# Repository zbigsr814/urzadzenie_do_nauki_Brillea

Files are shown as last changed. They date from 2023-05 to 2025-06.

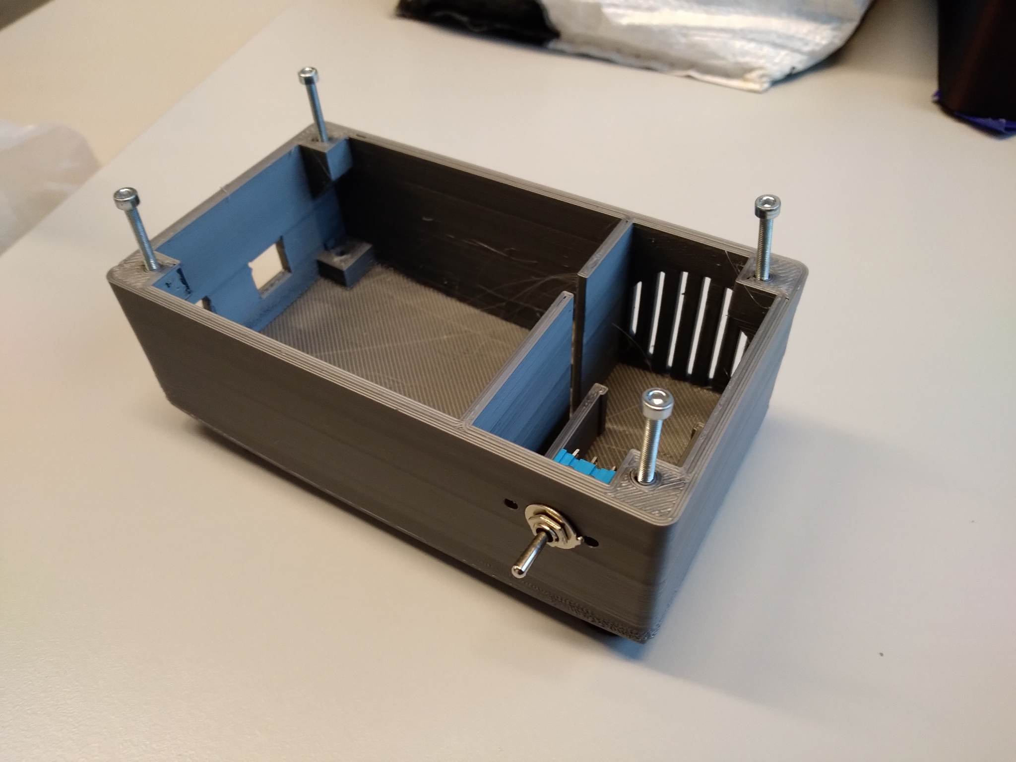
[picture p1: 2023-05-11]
zdjęcia i filmy/7.jpg

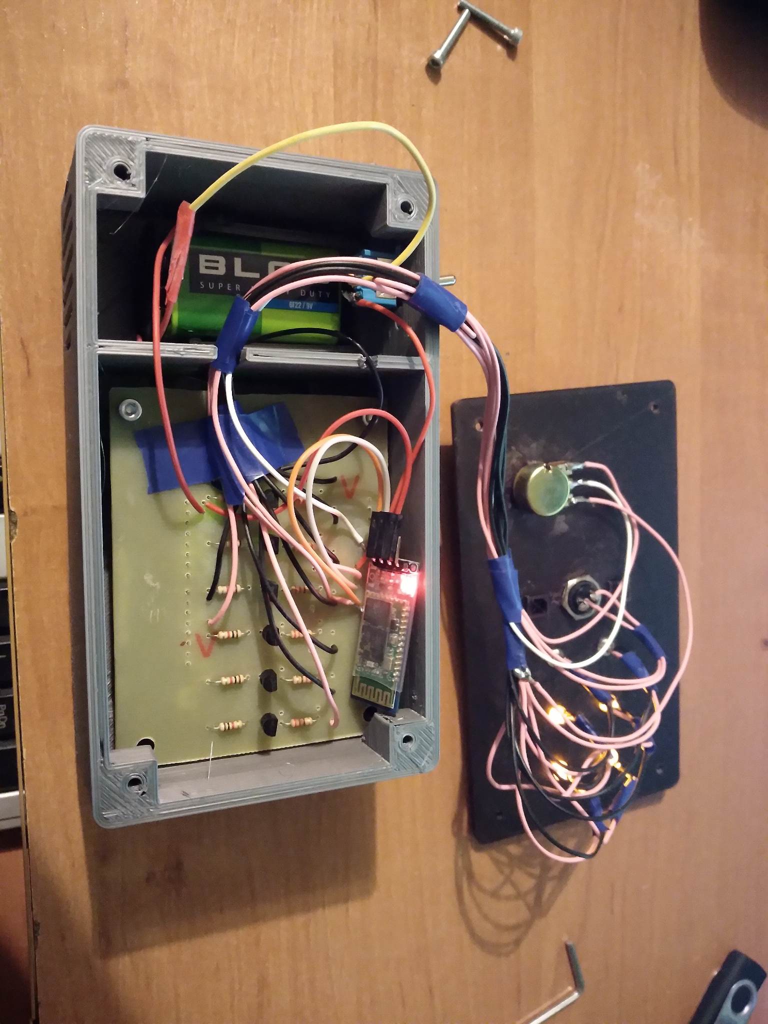
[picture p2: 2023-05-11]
zdjęcia i filmy/4.jpg

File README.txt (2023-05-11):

# urzadzenie_do_nauki_Brillea

Wykonany projekt został zrealizowany dla koła naukowego Integral Senso na PŚ. 
 
Jest to urządzenie do nauki języka Brillea dla dzieci niedowidzących. Urządzenie odbierało dane z czujnika HC-05 (wyrazy/zdania) przesłane z telefonu (przez sieć Bluetooth) i wyświetlał je w alfabecie Brillea. Należało pobrać aplikację na telefon która funkcjonyje jako terminal Bluetooth. Wyświetlanie liter alfabetu Brillea odbywało się przez sześć diod, iteracja po kolejnych literach przez wciśnięcie przycisku. Regulacja jasności świecenia diodami potencjometrem. Sygnał z potencjometru trafiał na wejście analogowe Arduino. Regulacja świecenia diod przez PWM pinów wyjściowych Arduino. Zasilanie wewnętrzne bateryjne oraz zewnętrzne przewodem USB do źródła zasilania. Projekt obejmował: 

- Wykonanie programu na Arduino. Program odpowiedzialny za: obsługę odbioru danych przez Bluetooth, wysterowanie odpowiednich diod, sterowanie jasnością świecenia, odbiór danych z potencjometru.

- Projekt płytki PCB w Kicadzie. Płytka odpowiada m.in. za wzmocnienie sygnałów GPIO Arduino przez zastosowanie tranzystorów BC-547. Wzmocnione sygnały docierają na diody. Płytka pośredniczy między Arduino a resztą urządzenia. 
 
- Projekt obudowy urządzenia wykonanej w DesignSparks. Urządzenie miało być przeznaczone dla dzieci więc obudowa nie zawierała ostrych krawędzi, ścianki obudowy są odpowiednio grube. Wyznaczono sekcję dla zasilania bateryjnego i dla reszty elektroniki. Obudowę wykonano na drukarce 3D.

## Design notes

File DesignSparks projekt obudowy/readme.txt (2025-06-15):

Górna i dolna część zamodelowanej obudowy. Model następnie był poddany obróbce przez Cura Slicer aby uzyskać g-code do drukarki 3D. 
Modele obudowy w formacie stl można podpatrzeć klikając na nie. Do podglądu można też wykorzystać stronę: https://www.viewstl.com/
Plik w formacie rsdoc to zamodelowany projekt w programie Design Sparks

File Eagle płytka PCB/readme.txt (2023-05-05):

Pliki brd i sch w tym katalogu to gotowe pliki do uruchmienia w programie Kicad.

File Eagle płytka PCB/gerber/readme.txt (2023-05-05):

Model płytki PCB można zobaczyć na stronie: https://www.pcbway.com/project/OnlineGerberViewer.html

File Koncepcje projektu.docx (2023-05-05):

Cel projektu:

- budowa urządzenia dla dzieci, które miało im pomóc w nauce języka Brille’a. Zabawka ma służyć aby wywołać w dziecku pozytywne emocje, aby czymś te dziecko zająć oraz w celu dydaktyki i nauki nowego języka. Wstępnie dokonano różnego rodzaju koncepcji aby gotowe urządzenie spełniało szereg wymagań.

Postanowionymi wymaganiami było m.in.:

- niski koszt budowy urządzenia

- prosta zasada działania urządzenia

- urządzenie ma bezpośrednio oddziaływać na zmysły użytkownika (wzrok, odczuwanie itd.)

- wysoka wytrzymałość urządzenia

- możliwość konfiguracji przedstawiania danych wyjściowych

Pierwszym założeniem jakie przyjęto podczas realizacji projektu jest funkcja oddziaływania urządzenia na zmysł wzroku dziecka. Docelowo język Brille’a jest językiem którym posługują się osoby niewidome i niedowidzące. Postanowiono że istnieje szereg chorób tj. zaćma lub jaskra w wyniku których osoba stopniowo traci wzrok. Kiedy wzrok osoby jest jeszcze dostatecznie dobry to jest w stanie nauczyć się języka Brille’a za pomocą wzroku. Przykładowym sposobem jest wykorzystanie diod LED lub innego źródła światła aby oddziaływać na zmysł wzroku dziecka.

Realizacja projektu:

Platforma sprzętowa

W pierwszej kolejności należało określić jaka platforma sprzętowa zostanie wybrana. Poniższe platformy są dosyć popularne i łatwo dostępne. Dokonano rozważania między poniższymi platformami:

- Arduino – platforma programistyczna dla systemów wbudowanych oparta na prostym projekcie Open Hardware przeznaczonym dla mikrokontrolerów montowanych w pojedynczym obwodzie drukowanym, z wbudowaną obsługą układów wejścia/wyjścia oraz standaryzowanym językiem programowania.

Zalety: prosta budowa, przyjazny język programowania dla hobbystów, niska cena.

Wady: napisane programy zajmują więcej miejsca, programy są mało optymalne, mała ilość pamięci Flash, RAM, EEPROM

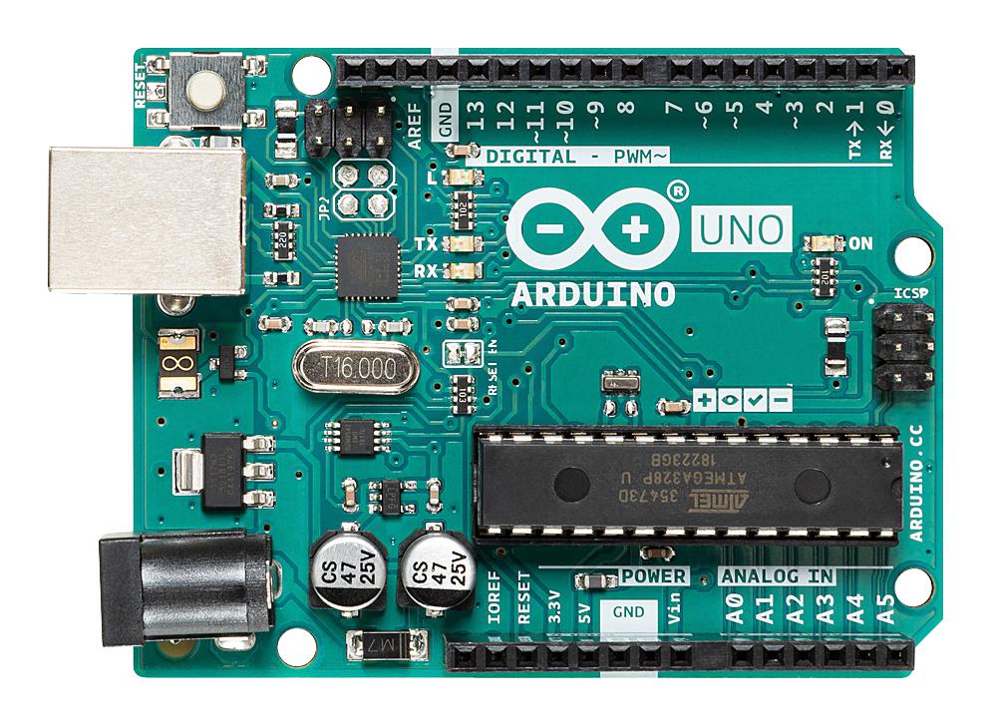
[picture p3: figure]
A000066 - Arduino - Płytka ewaluacyjna, MCU 8 bitów, Arduino Uno R3

Rys. x Arduino Uno

- STM32 - rodzina 32–bitowych mikrokontrolerów w układach scalonych produkowanych przez francusko-włoską firmę STMicroelectronics. Chipy STM32 są pogrupowane w różne, blisko spokrewnione serie, oparte na 32–bitowych procesorach ARM, takich jak Cortex-M7F, Cortex-M4F, Cortex-M3, Cortex-M0 + lub Cortex-M0.

Zalety: duża ilość pamięci RAM, EEPROM, Flash, wysoka częstotliwość taktowania, duża ilość urządzeń peryferyjnych, programowanie w C

Wady: wysoka cena płytek rozwojowych

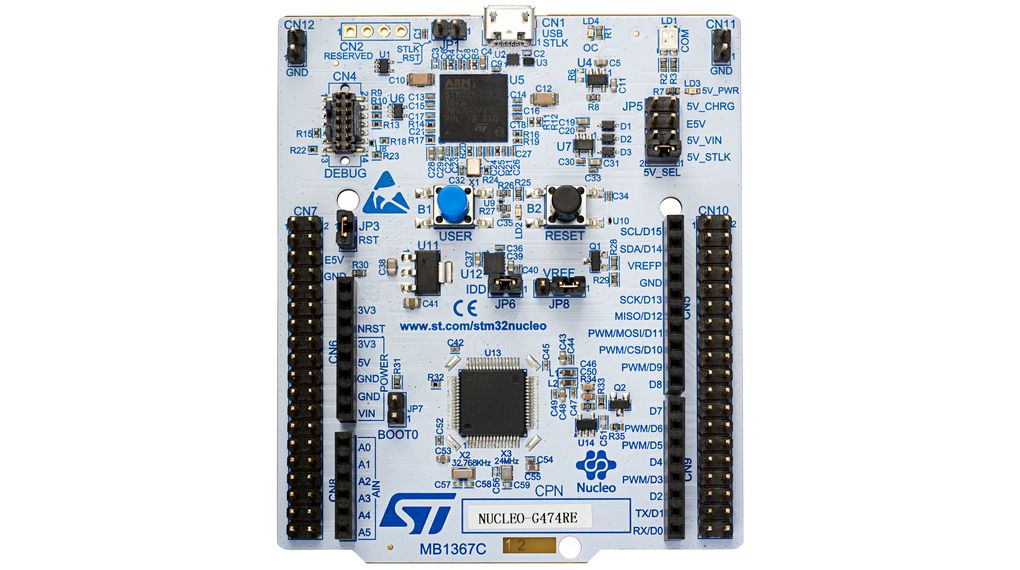
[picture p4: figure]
NUCLEO-L452RE-P | ST Płytka Nucleo STM32 512KB 160KB | Distrelec Polska

Rys. x STM32

- AVR - Mikrokontrolery AVR są popularne wśród hobbystów i amatorów, ze względu na łatwość programowania, a także łatwość uruchomienia. Do niektórych układów wystarczy podłączyć zasilanie, by stanowiły kompletny, programowalny system mikroprocesorowy. W połączeniu z dużymi obudowami typu DIP daje to rzadko spotykaną możliwość budowy prostszych układów mikroprocesorowych bez konieczności pracochłonnego przygotowywania płytki drukowanej.

Zalety: prosta budowa, programowanie w C, niska cena.

Wady: mała ilość pamięci Flash, RAM, EEPROM

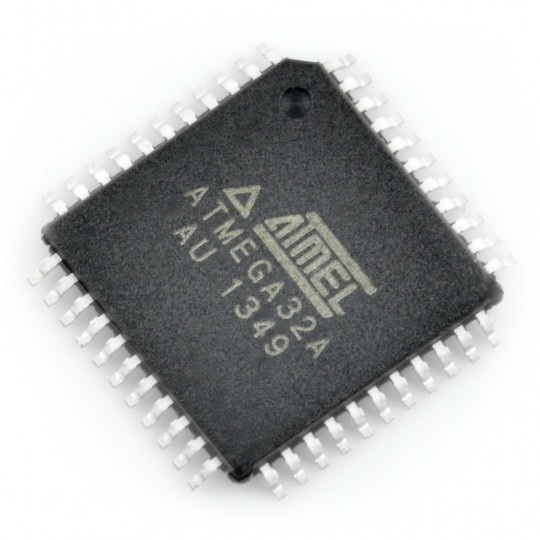
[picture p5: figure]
Mikrokontroler AVR - ATmega32A-AU SMD

Rys. x AVR

Na podstawie powyższych rozważań, zdecydowano się na platformę Arduino Uno. Arduino posiada prosty język programowania oraz cena nie jest wysoka. Dodatkowo wysoka częstotliwość taktowania czy duża ilość urządzeń peryferyjnych nie jest wymagana dla projektu jakim jest zabawka dla dzieci.

Źródło światła

W następnej kolejności skupiono się nad możliwymi źródła światła. Przyjęto że najlepszym rozwiązaniem będą diody LED. Diody muszą być w kolorze który będzie łatwo odbieranym przez dziecko. Diody muszą być w przezroczystej obudowie. Rozważano następujące rodzaje diod:

- diody w kolorze żółtym – kolor żółty jest łatwo odczytywanym przez dziecko. Ten kolor łatwo będzie kontrastował na ciemnym tle (na obudowie urządzenia w ciemnym kolorze)

- diody RGB – jest to rozwiązanie uniwersalne. Użytkownik będzie miał możliwość wybrania koloru wedle upodobania.

Dokonanym wyborem są diody LED w przezroczystej obudowie świecące kolorem żółtym. Wykorzystanie monochromatycznego światła jest wystarczające dla tego projektu. Dodatkową funkcjonalnością dodaną do projektu jest dodanie potencjometru, którym możemy regulować jasność świecenia diod.

Zasilanie

Rozważano następujące sposoby zasilania:

- zasilanie z USB – najbardziej uniwersalne rozwiązanie. Wystarczy przewód USB którym podłączymy się do urządzenia. Źródłem zasilania może być zewnętrzny powerbank lub zasilacz podłączony do sieci.

- zasilanie bateryjne – rozwiązanie do którego nie potrzeba dodatkowych przewodów lub zasilaczy. Wadą tego zastosowania jest częsta zmiana baterii na skutek używania urządzenia

- zasilanie z wewnętrznego powerbanka – kolejnym rozwiązaniem jest zamontowanie powerbanka wewnątrz obudowy. To rozwiązanie ma tą zaletę że powerbank pomieści dużą ilość prądu, konieczne będzie ładowanie z USB.

Dokonano wyboru dwóch powyższych opcji. Zastosowano zasilanie bateryjne oraz poprzez USB. Jeśli bateria się zużyje to należy ją wymienić, lecz będzie też można zasilić urządzenie z zewnętrznego powerbanka lub zasilacza.

Obudowa urządzenia

Zdecydowano się wykonać obudowę urządzenia z plastiku. Obudowę wykonano na drukarce 3D. Kolor obudowy musi być w ciemnym kolorze tak aby jasne świecące diody mogły kontrastować z ciemnym tłem.

Źródła:

https://www.google.com/url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 (https://www.google.com/url?psig=AOvVaw3-AJc7bmiJPXDSjU2i4-T9&cd=vfe)

https://www.google.com/url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 (https://www.google.com/url?psig=AOvVaw25d-h0V1c4RtG5vNDJ4lyy&cd=vfe)

https://botland.com.pl/avr-smd/160-mikrokontroler-avr-atmega32a-au-smd-5903351249935.html

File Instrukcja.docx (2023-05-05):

Instrukcja do urządzenia do nauki Brille’a z diodami.

1. W pierwszej kolejności należy włączyć urządzenie. Są na to dwa sposoby. Pierwszy sposób to przez zmianę położenia przełącznika z boku obudowy. Drugi sposób to podłączenie kabla USB do urządzenia. Drugi koniec kabla należy podłączyć do powerbanka lub do zasilacza. Jeśli urządzenie się załączy to jedna z diod kilkukrotnie zamiga.
2. W następnej kolejności należy na telefonie przejść do aplikacji Sklep Play. Należy odszukać i zainstalować aplikację: Bluetooth Terminal HC-05.

Rys. 1. Ikona aplikacji

Aplikację możemy pobrać też po wpisaniu poniższego linku do przeglądarki internetowej:

https://play.google.com/store/apps/details?id=project.bluetoothterminal

3. Po zainstalowaniu należy uruchomić aplikację. Na początku zostaniemy zapytani czy włączyć funkcję Bluetooth w telefonie. Należy zezwolić na włączenie Bluetooth.

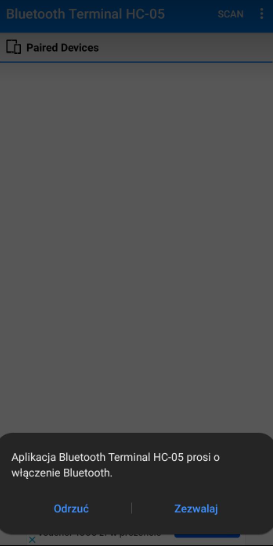
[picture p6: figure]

Rys. 2. Początkowy ekran w aplikacji

4. Następnie w aplikacji należy sparować się z urządzeniem HC-05:
5. Uruchomi się główne okno aplikacji. W miejscu „Enter ASCII Command” należy wpisać tekst jaki chcemy przesłać do urządzenia. Następnie klikamy przycisk „Send ASCII” w celu wysłania tekstu.

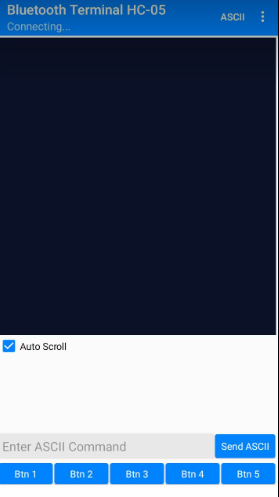
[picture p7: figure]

Rys. 3. Główne okno aplikacji

6. W tym momencie w urządzeniu powinny zapalić się diody odpowiadające wysłanemu wcześniej tekstowi. Diody świecą się zgodnie z alfabetem Brille’a. Aby przejść do następnej litery wysłanego tekstu, należy wcisnąć czerwony przycisk. Urządzenie ma możliwość regulowania jasności świecenia diod. Służy do tego pokrętło w dolnej części obudowy.
7. Po wyświetleniu wszystkich liter nadesłanego słowa, możemy wysłać nowy napis przez aplikację na telefonie.
8. Po zakończeniu użytkowania urządzenia należy je wyłączyć poprzez odłączenie przewodu USB (jeśli stosowano zewnętrzne zasilanie) lub zmienić pozycję przełącznika z boku obudowy (jeśli stosowano wewnętrzne bateryjne zasilanie).

Urządzenie posiada zasilanie bateryjne. Jeśli bateria jest rozładowana to urządzenie się nie włączy. Należy albo wymienić baterię (Należy odkręcić cztery śruby obudowy), albo zasilić urządzenie z zewnątrz poprzez kabel USB.

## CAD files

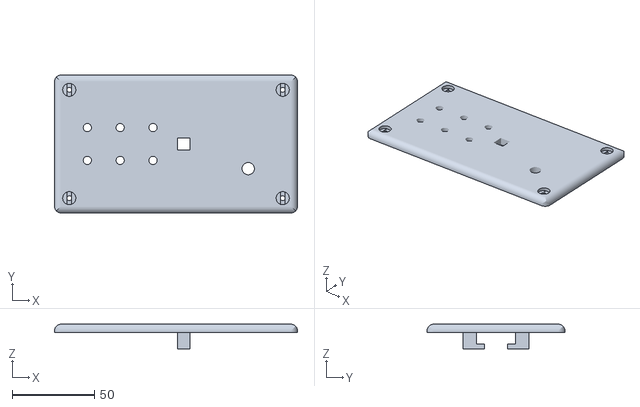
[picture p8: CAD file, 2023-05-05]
DesignSparks projekt obudowy/ObudowaGoraSTL.stl
148.0 x 84.0 x 15.0

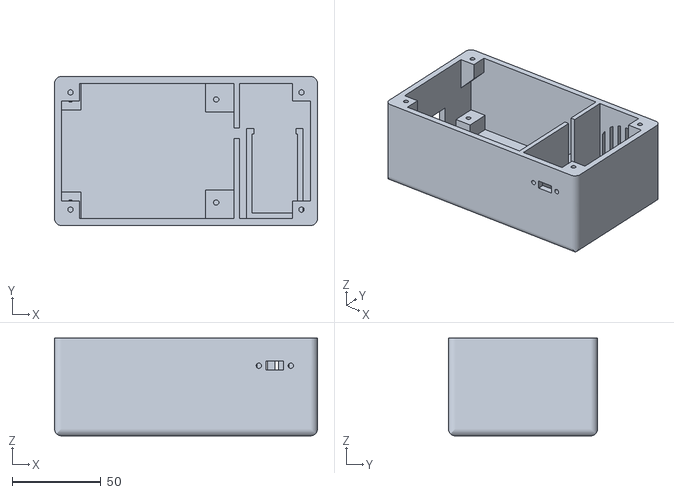
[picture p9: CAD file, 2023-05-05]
DesignSparks projekt obudowy/ObudowaSpodSTL.stl
148.0 x 84.0 x 55.0

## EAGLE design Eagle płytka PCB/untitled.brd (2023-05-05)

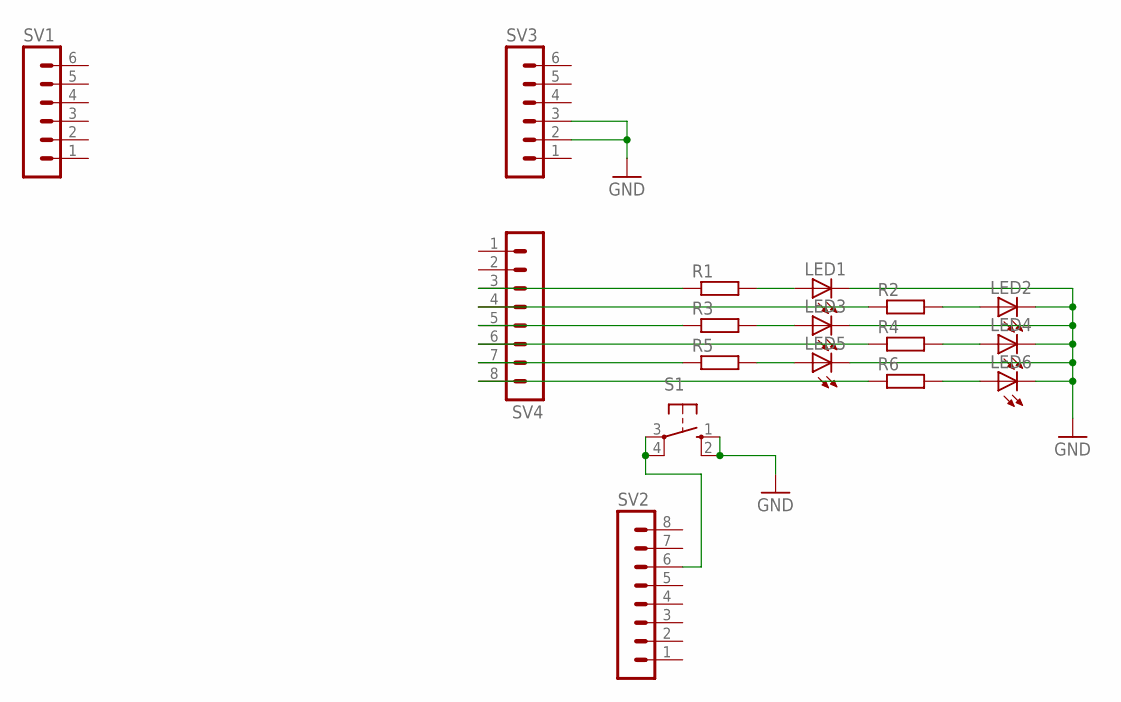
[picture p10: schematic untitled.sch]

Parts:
LED1, LED2, LED3, LED4, LED5, LED6: LED3MM
R1, R2, R3, R4, R5, R6: R-EU_0207/10; 0207/10
S1: 40-XX; B3F-40XX
SV1, SV3: MA06-1
SV2, SV4: MA08-1

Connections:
GND: LED1.K (C), LED2.K (C), LED3.K (C), LED4.K (C), LED5.K (C), LED6.K (C), S1.1 (S), S1.2 (S1), SV3.2, SV3.3
unnamed: R6.1, SV4.8
unnamed: LED4.A, R4.2
unnamed: R5.1, SV4.7
unnamed: LED2.A, R2.2
unnamed: LED3.A, R3.2
unnamed: R4.1, SV4.6
unnamed: R3.1, SV4.5
unnamed: LED1.A, R1.2
unnamed: LED5.A, R5.2
unnamed: R2.1, SV4.4
unnamed: R1.1, SV4.3
unnamed: LED6.A, R6.2
unnamed: S1.3, S1.4 (P1), SV2.6

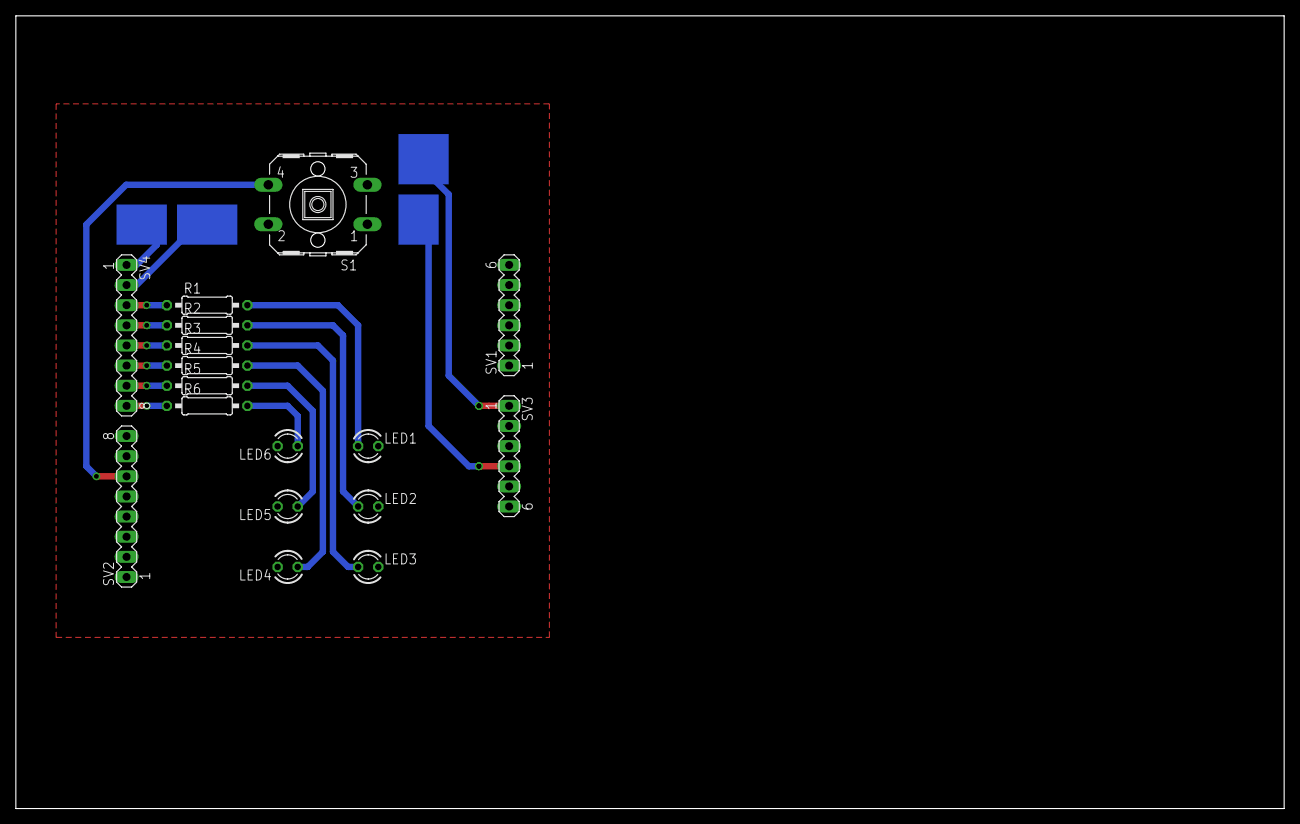
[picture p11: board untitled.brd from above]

Board: 2 copper layers, 160.0 x 100.0 mm, 17 parts (0 on the bottom side), 14 nets.

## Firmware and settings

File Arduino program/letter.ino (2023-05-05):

//#include <Vector.h>
#include <SoftwareSerial.h>
#include "letter.h"
SoftwareSerial hc06(0,1);
#define Led5 2
#define Led4 3
#define Led0 4
#define Led2 11
#define Led3 12
#define Led1 13
#define button 10
int16_t readData = 0, i = 0;

void setup() 
{
  Serial.begin(9600);
  Serial.println("słowo:");
  hc06.begin(9600);
  pinMode(Led0, OUTPUT);
  pinMode(Led1, OUTPUT);
  pinMode(Led2, OUTPUT);
  pinMode(Led3, OUTPUT);
  pinMode(Led4, OUTPUT);
  pinMode(Led5, OUTPUT);
  digitalWrite(Led0, LOW);
  digitalWrite(Led1, LOW);
  digitalWrite(Led2, LOW);
  digitalWrite(Led3, LOW);
  digitalWrite(Led4, LOW);
  digitalWrite(Led5, LOW);
  pinMode(button, INPUT_PULLUP);    
}

void loop() 
{
 String zdanie = ""; 
 if(hc06.available()>0)
 {
   zdanie=Serial.readStringUntil('\n');
   zdanie.toLowerCase();
    
   Letters x(zdanie);
   for(int j=0;j<zdanie.length();j++)
   {
      Braille *y = x.table[j];
      for(int i=0; i<6;i++)
      {
        Serial.println(y->table[i]);
      }

      
      while(digitalRead(button) == HIGH)
      {
        readData = (analogRead(A0))/8;
        i++;
        if(i == 110) i = 0;
             
        if(i < readData)
        {
          
          if(y->table[0]==1)
          {
            digitalWrite(Led0, HIGH);
          }
          if(y->table[1]==1)
          {
            digitalWrite(Led1, HIGH);
          }
          if(y->table[2]==1)
          {
            digitalWrite(Led2, HIGH);
          }
          if(y->table[3]==1)
          {
            digitalWrite(Led3, HIGH);
          }
          if(y->table[4]==1)
          {
            digitalWrite(Led4, HIGH);
          }
          if(y->table[5]==1)
          {
            digitalWrite(Led5, HIGH);
          }
        }
        else
        {
          digitalWrite(Led0, LOW);
          digitalWrite(Led1, LOW);
          digitalWrite(Led2, LOW);
          digitalWrite(Led3, LOW);
          digitalWrite(Led4, LOW);
          digitalWrite(Led5, LOW);
        }
      }
      
    digitalWrite(Led0, LOW);
    digitalWrite(Led1, LOW);
    digitalWrite(Led2, LOW);
    digitalWrite(Led3, LOW);
    digitalWrite(Led4, LOW);
    digitalWrite(Led5, LOW);
    delay(1000);
 }
 }

}

void blinkAll()
{
  digitalWrite(Led0, HIGH);
  digitalWrite(Led1, HIGH);
  digitalWrite(Led2, HIGH);
  digitalWrite(Led3, HIGH);
  digitalWrite(Led4, HIGH);
  digitalWrite(Led5, HIGH);
  delay(1000);
  digitalWrite(Led0, LOW);
  digitalWrite(Led1, LOW);
  digitalWrite(Led2, LOW);
  digitalWrite(Led3, LOW);
  digitalWrite(Led4, LOW);
  digitalWrite(Led5, LOW);
}
